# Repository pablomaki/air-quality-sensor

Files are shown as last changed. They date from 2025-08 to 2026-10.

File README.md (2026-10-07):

# Air Quality Sensor

This repository contains the firmware, hardware design, and scripts for an indoor air quality sensor.

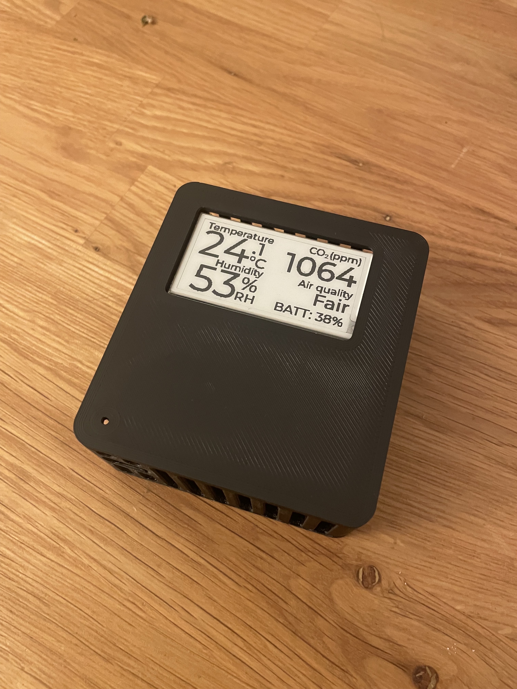
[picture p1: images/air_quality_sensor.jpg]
Air Quality Sensor


## Features

- **Supported Sensors**: The system supports a variety of sensors for measuring air quality parameters such as:
  - **SHT40/SHT41** temperature and humidity sensor
  - **SGP40** VOC (Volatile Organic Compound) sensor
  - **SCD40/SCD41** Carbon Dioxide (CO2) sensor (includes temperature and humidity reading as well)
  - **BMP390** Pressure sensor
  - **BME680** Gas, humidity, pressure and temperature sensor
- **Electronic paper display**: Support for an Electronic paper display for displaying the measured values.
- **Wireless Communication**: Matter over Thread, so the sensor works with any Matter controller (Apple Home, Google Home, Home Assistant). Bluetooth Low Energy is used only for commissioning.
- **Battery powered**: Battery life sensor and measurement/advertisement frequency dependent, but the default configurations aim for 1+ month up time.
- **Dockerized data receiver**: Joins the sensor's Matter fabric as a second administrator, alongside the smart home controller, and republishes the measurements to Prometheus and to an MQTT server ([MQTTThing](https://github.com/arachnetech/homebridge-mqttthing)).

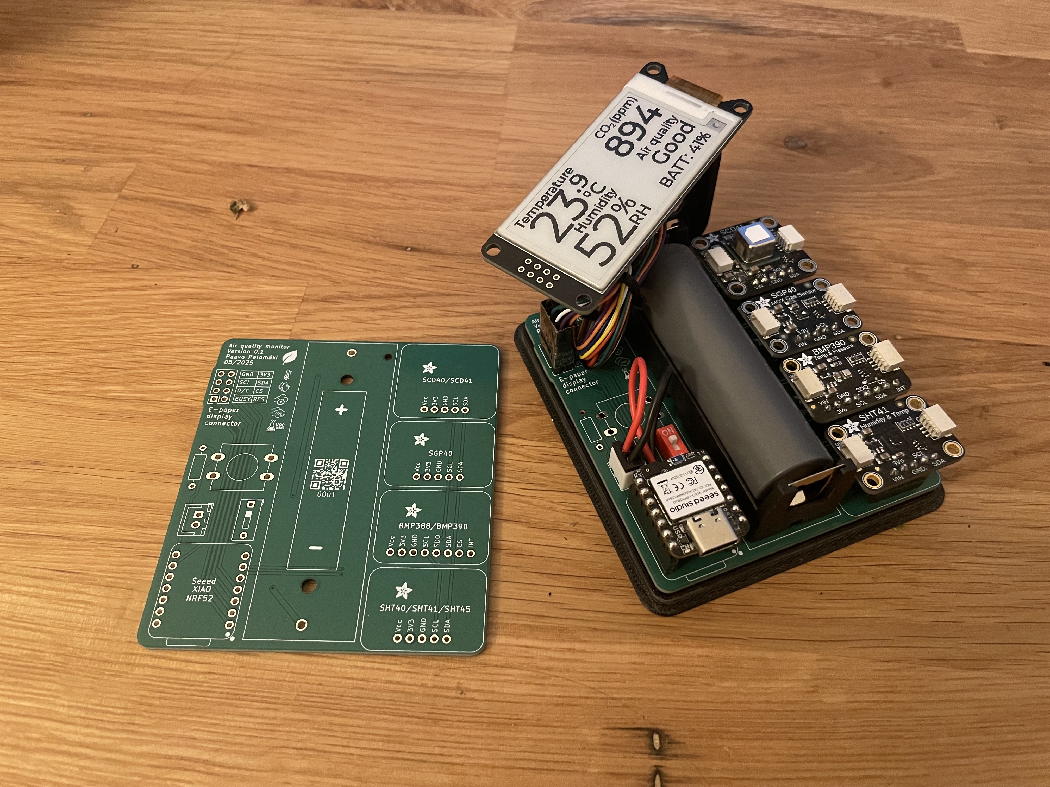
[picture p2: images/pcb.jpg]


## Structure

- **docker/**: Contains Docker configuration files for setting up the Matter sensor reader.
- **firmware/**: Contains the firmware source code and build files for the air quality sensor.
- **pcb/**: Contains the design files for the air quality sensor PCB.
- **enclosure/**: Contains the design files for the air quality sensor enclosure.
- **scripts/**: Contains utility scripts for reading the air quality sensor over Matter and forwarding the data to Prometheus and MQTT, used by the docker image.

Refer to the README files in each subdirectory for more details.

## TODO
- **Firmware**
    -
- **PCB**
    -
- **Scripts**
    -
- **Other**
    -

## License

This project is licensed under the terms specified in the `LICENSE` file.

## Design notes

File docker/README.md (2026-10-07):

# Docker

Deployment for the host that reads the air quality sensors over Matter and
forwards their measurements to Prometheus and MQTT.

## Files

- **docker-compose.yml**: Defines the Matter server and the bridge service.
- **Dockerfile**: Builds the image for the scripts in [scripts/](../scripts/).

## Services

- **matter-server**: Upstream
  [python-matter-server](https://github.com/home-assistant-libs/python-matter-server).
  It owns the Matter fabric, holds the subscriptions to the sensors and exposes
  them on a WebSocket API at port 5580. Its fabric credentials live in
  `./matter-server-data`, so back that directory up - losing it means
  re-commissioning every sensor.
- **aqs_matter_client**: The bridge, serving Prometheus metrics on port 8000.

Both run with `network_mode: host`, which is required: Matter needs IPv6 and
mDNS on the LAN to reach the sensors through the Thread border router, and
neither survives Docker's default bridge network. See the
[scripts README](../scripts/README.md) for the IPv6 route configuration the host
itself needs.

Unlike the old BLE setup there is one bridge container for all sensors, not one
per sensor - they share a single Matter fabric, and metrics are told apart by
the `sensor` label.

## Usage

Review the environment variables in `docker-compose.yml`, in particular
`NODE_NAMES` and the MQTT broker settings, then start both services:

```bash
docker compose up -d --build
```

Commission the sensors into the fabric before expecting any metrics; the
[scripts README](../scripts/README.md) covers that. To check that the bridge
works, follow its logs:

```bash
docker compose logs -f aqs_matter_client
```

Or scrape the metrics endpoint directly:

```bash
curl -s http://localhost:8000/metrics | grep aqs_
```

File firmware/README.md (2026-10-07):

# Air Quality Sensor Firmware for nRF52840

## Overview

This firmware runs on the Seeed XIAO nRF52840 (Sense) board. It reads a set of air
quality sensors over I2C and exposes the readings as a **Matter over Thread** device,
so the node can be commissioned into any Matter ecosystem.

### Key Features

- **Sensor Support**: The firmware supports the following sensors. Which of them are
  present is decided by the board overlay, see [Sensor selection](#sensor-selection):
  - **SHT40/SHT41** temperature and humidity sensor
  - **SGP40** VOC (Volatile Organic Compound) sensor
  - **SCD40/SCD41** Carbon Dioxide (CO2) sensor (also measures temperature and humidity,
    used as a fallback when no dedicated sensor is present)
  - **BMP390** pressure sensor
  - **BME680** gas/IAQ sensor (requires the `bsec` west manifest group, see
    [Prerequisites](#prerequisites))
- **Matter over Thread**: The node is commissioned over Bluetooth LE and then reports
  over Thread. Bluetooth LE is used only for commissioning.
- **Configurable sampling and reporting**: Independent intervals, see
  [Configuration](#configuration).
- **Per-board identity from one binary**: The onboarding values compiled into the
  image are only fallbacks, see [Device identity](#device-identity).
- **Factory reset without a button**: Power cycle the device five times in a row,
  see [Factory reset](#factory-reset).

### Matter data model

Each quantity is reported on its own endpoint so that ecosystems surface them as
separate sensors:

| Endpoint | Device type | Reports |
| --- | --- | --- |
| 1 | Temperature Sensor | temperature |
| 2 | Humidity Sensor | relative humidity |
| 3 | Pressure Sensor | pressure |
| 4 | Air Quality Sensor | air quality, CO2 concentration |

A quantity with no valid reading is reported as `null` rather than as a placeholder
value, so an unavailable sensor is distinguishable from a working one.

### Device identity

Factory data is disabled, so serial number, unique ID and setup discriminator would
otherwise come from the image and be identical on every board flashed with it - two
units would then present themselves to a controller as the same device. Instead
`src/components/device_identity.cpp` derives all three from the SoC's factory
programmed device ID on every boot and persists them:

| Value | Derivation |
| --- | --- |
| Serial number | `AQS-` followed by the device ID in hex |
| Unique ID | Salted SHA-256 of the device ID, so it is not the serial number restated |
| Setup discriminator | 12 bits of that same hash |

The derivation is deterministic, so a board keeps its identity across a factory reset
and a controller recognises a recommissioned unit as the same device. The setup
*passcode* is still shared, because a per-board one needs a SPAKE2+ verifier generated
on the device, which belongs with real factory data.

Because the discriminator now differs per board, the pairing code does too. Read it
from the log at startup, where the stack prints the QR code payload and the manual
pairing code - see [Viewing the log output](#viewing-the-log-output).

### Factory reset

A commissioned device stops advertising over Bluetooth LE, so if its fabric ever
becomes unusable it cannot be recommissioned without first being erased. The assembled
board carries no button, and flashing a `.uf2` does not help: the image is written to
the application partition only, leaving the settings partition that holds the
commissioning state untouched.

**Power cycle the device five times in a row**, leaving it powered for less than five
seconds each time. The LED blinks once per counted cycle. On the fifth the device
withdraws its records from the border router, erases the settings partition and
reboots uncommissioned, ready to be commissioned again.

Staying powered past the window drops the count, so ordinary restarts never accumulate.
Both numbers are configurable, see [Other settings](#other-settings).

## Building and Running

### Prerequisites

To build the project, ensure you have the following tools installed:

- [Visual Studio Code](https://code.visualstudio.com/download)
- [nRF Connect for Visual Studio Code](https://docs.nordicsemi.com/bundle/nrf-connect-vscode/page/get_started/install.html)
- nRF Connect SDK and Toolchain version 3.2.4 or newer

  > **Do not use v3.2.1.** Its `i2c_nrfx_twi` driver compares the transfer result
  > against `NRFX_SUCCESS` (0x0BAD0000) while the event handler stores 0 on success,
  > so every I2C transfer reports `-EIO` and no sensor is ever detected. The XIAO BLE
  > uses this driver for `i2c1`, where all the sensors live. Fixed in v3.2.4.

- The `bme68x` and `bsec` Bosch libraries (needed for `CONFIG_BME68X_IAQ`) belong to the
  `bsec` west manifest group, which is disabled by default. Enable it and fetch the
  sources before building:

  ```
  west config manifest.group-filter -- +bsec
  west update bme68x bsec
  ```

### Build Instructions

1. Clone the repository and navigate to the `firmware/` directory.
2. Open the project in Visual Studio Code.
3. Configure the build environment using the nRF Connect extension (v3.2.4 SDK and toolchain).
4. Build for the board target `xiao_ble/nrf52840/sense`.
5. Selecting "No sysbuild" might be necessary to avoid build issues.

Flash by copying the resulting `build/zephyr/zephyr.uf2` onto the mass storage device
that the Adafruit UF2 bootloader presents after double tapping reset. The firmware
deliberately does not use MCUboot, so that bootloader is left untouched.

### Viewing the log output

The console is a USB CDC ACM port provided by the board, not a UART. After flashing,
a second USB device enumerates; connect to it at any baud rate:

```
minicom -D /dev/ttyACM0
```

## Configuration

Settings live in `prj.conf` and are defined in `Kconfig`. There is no `config.h`.

### Sensor selection

The board overlay in `boards/` is the single source of truth for which parts exist on
the board. Adding a node there enables both the Zephyr driver and the application
support for it, because each `CONFIG_ENABLE_*` symbol depends on the corresponding
devicetree node and defaults to `y`. Use `prj.conf` only to turn a present sensor
*off*:

```
CONFIG_ENABLE_SHT4X=n   # part is on the board but not used in this build
```

Flash is very tight on this target, so check the memory report after a build and
enable sensors one at a time.

`CONFIG_BME68X_IAQ` is the exception: it is the licensed Bosch BSEC path, has no
devicetree default, and is mutually exclusive with the plain `CONFIG_BME680` driver.

### Timing

| Symbol | Default | Meaning |
| --- | --- | --- |
| `CONFIG_SAMPLE_INTERVAL_MS` | 5000 | How often every enabled sensor is read. Also the sampling interval given to the Sensirion gas index algorithm. |
| `CONFIG_REPORT_INTERVAL_MS` | 60000 | How often the Matter attributes are refreshed from the buffered samples. |

The two are independent. The number of samples averaged into each reported value is
derived from them - one reporting period's worth - so every sample taken contributes
to exactly one report.

Note that when a controller actually *receives* a value is governed by its own Matter
subscription intervals, not by `CONFIG_REPORT_INTERVAL_MS`, which only controls how
fresh the attributes are.

### Other settings

| Symbol | Meaning |
| --- | --- |
| `CONFIG_ENABLE_EVENT_LED` | Blink the RGB LED on application events |
| `CONFIG_FACTORY_RESET_POWER_CYCLES` | Power cycles in succession that trigger a factory reset |
| `CONFIG_FACTORY_RESET_POWER_CYCLE_WINDOW_MS` | How long the device must stay up before the count is dropped |
| `CONFIG_SCD4X_ALTITUDE` | Altitude in metres, used when no pressure sensor supplies compensation |
| `CONFIG_SCD4X_TEMPERATURE_OFFSET_MILLI_C` | Compensates the SCD4x self heating, in milli-degrees Celsius (2.35 degrees = 2350) |

## Additional Resources

- [Nordic Semiconductor Documentation](https://docs.nordicsemi.com/)
- [Seeed XIAO nRF52840 Documentation](https://wiki.seeedstudio.com/XIAO_nRF52840/)

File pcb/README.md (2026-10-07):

# PCB Design

This directory contains the PCB design files for the air quality sensor.

## Files

- **air-quality-sensor-pcb.kicad_pcb**: The PCB layout file.
- **air-quality-sensor-pcb.kicad_prl**: Project-related layout file.
- **air-quality-sensor-pcb.kicad_pro**: KiCad project file.
- **air-quality-sensor-pcb.kicad_sch**: The schematic file for the PCB design.
- **gerber.zip**: Gerber files for ordering the PCB.

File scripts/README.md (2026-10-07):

# Scripts

Utility scripts for reading the air quality sensor over Matter and forwarding its
measurements to Prometheus and MQTT.

The sensor is a Matter over Thread device. It has no vendor cloud and no local
HTTP API, so the only way to read it is to speak Matter to it. This host does
that by joining the sensor's Matter fabric as a second administrator, alongside
Apple Home - Matter's multi-admin support means both controllers see the device
at the same time and neither disturbs the other.

Reading the values back out of Apple Home instead is not possible: Apple exposes
no local API for accessory state, so the data has to come from the device.

## Files

- **aqs_matter_client.py**: Subscribes to the sensors' Matter attributes through
  a [python-matter-server](https://github.com/home-assistant-libs/python-matter-server)
  instance, exposes them as Prometheus metrics and publishes them to MQTT.
- **aqs_matter_commission.py**: Joins a sensor to this host's Matter fabric.
- **aqs_matter_nodes.py**: Lists the nodes on the fabric and removes unwanted ones.

Both scripts are run by the containers defined in [docker/](../docker/); see that
directory's README for the deployment.

## Exported metrics

Every metric carries `sensor` and `node_id` labels, so one process serves all
sensors on the fabric.

| Metric | Unit | Matter cluster |
| --- | --- | --- |
| `aqs_temperature_celsius` | °C | Temperature Measurement (0x0402) |
| `aqs_humidity_percent` | % RH | Relative Humidity Measurement (0x0405) |
| `aqs_pressure_hpa` | hPa | Pressure Measurement (0x0403) |
| `aqs_co2_ppm` | ppm | CO2 Concentration Measurement (0x040D) |
| `aqs_air_quality` | 0 unknown … 6 extremely poor | Air Quality (0x005B) |
| `aqs_node_available` | 0 or 1 | reachability, from the Matter server |
| `aqs_last_update_timestamp_seconds` | unix time | last attribute report received |
| `aqs_bridge_connected` | 0 or 1 | bridge to Matter server connection |

A measurement the firmware reports as null - no valid sample - is removed from
the metrics rather than published as zero, so it reads as absent in Prometheus.

The same values are published to MQTT as `<sensor name>/<measurement>`, matching
the topic layout the old BLE client used, with `air_quality` published as its
readable name for [MQTTThing](https://github.com/arachnetech/homebridge-mqttthing).

The VOC and IAQ indices the BLE firmware exposed are not available: the firmware
folds them into the Air Quality rating and does not publish the raw index over
Matter. Battery level is likewise not published.

## Dependencies

- **Python 3.9+**
- **`aiohttp`** - WebSocket client for the Matter server
- **`paho-mqtt`** - MQTT communication
- **`prometheus-client`** - Metrics collection and HTTP server
- A running **python-matter-server**, see [docker/](../docker/)

## Host setup

The sensor is a Thread minimal end device with no IP connectivity of its own.
This host reaches it over IPv6 through a Thread border router - an Apple TV or
HomePod if the sensor is in Apple Home - which advertises a route to the Thread
mesh prefix on the LAN. Linux ignores those advertisements by default, so enable
them for the LAN interface:

```bash
sudo tee /etc/sysctl.d/99-thread.conf <<'EOF'
net.ipv6.conf.eth0.accept_ra = 2
net.ipv6.conf.eth0.accept_ra_rt_info_max_plen = 64
EOF
sudo sysctl -p /etc/sysctl.d/99-thread.conf
```

Replace `eth0` with the actual interface. Verify that a route to the mesh prefix
appears, which needs the border router to be up:

```bash
ip -6 route show | grep -i fd
```

Containers speaking Matter must use host networking; IPv6 and mDNS do not
survive Docker's default bridge.

Matter discovers devices over mDNS, and its Linux implementation does that
through the host's Avahi daemon rather than resolving on its own. Avahi has to
be installed and running, and its D-Bus socket has to be visible to the Matter
server container - which is what the `/run/dbus` mount in the compose file is
for:

```bash
sudo apt install avahi-daemon
sudo systemctl enable --now avahi-daemon
```

## Adding a sensor to this host's fabric

If the sensor is already in Apple Home, open pairing mode there rather than
factory resetting it - that keeps the Apple Home pairing intact and adds this
host as a second administrator:

1. In the Home app, open the accessory's settings.
2. Choose *Turn On Pairing Mode* and note the setup code it shows.
3. Run the commissioning helper with that code:

```bash
docker exec -it aqs_matter_client python aqs_matter_commission.py 1234-567-8901
```

The helper prints the node id the sensor was assigned. Put it in `NODE_NAMES` in
[docker-compose.yml](../docker/docker-compose.yml) to control the `sensor` label
its metrics carry, then restart the bridge.

For a factory-fresh sensor that is not in any fabric yet, commissioning has to
run over Bluetooth and has to supply the Thread network credentials first. Start
the Matter server with `--bluetooth-adapter 0`, push the dataset, then pair with
the code from the sensor's onboarding label:

```bash
docker exec -it aqs_matter_client python aqs_matter_commission.py --ble 1234-567-8901
```

## Managing the fabric

List what the Matter server currently holds:

```bash
docker exec -it aqs_matter_client python aqs_matter_nodes.py list
```

A failed commissioning attempt leaves a node entry behind that will always read
as unreachable, because no device was ever paired to it. Remove those:

```bash
docker exec -it aqs_matter_client python aqs_matter_nodes.py remove 1 2
```

Removing a node that is genuinely paired also tells the device to drop this
fabric, so it stops reporting here; it stays in any other controller's fabric,
such as Apple Home. Removing a leftover entry only clears the server's own
storage, since there is no device on the other end to inform.

## Troubleshooting commissioning

`Commission with code failed` means the Matter server never completed the
pairing. The reason is in its own log, which is far more specific than the
helper's error:

```bash
docker compose logs --tail=100 matter-server
```

The usual causes, all of which the helper cannot distinguish between:

- **The device was never discovered.** Check that Avahi is running on the host
  and that the Matter server container has `/run/dbus` mounted. Confirm the
  sensor is actually advertising while pairing mode is open:

  ```bash
  avahi-browse -rt _matterc._udp
  ```

  An empty result means either pairing mode is closed or the border router is
  not relaying the Thread mesh's mDNS onto the LAN.

- **The device was discovered but could not be reached.** This is the IPv6 route
  described above: without it the host resolves the sensor's address and then
  cannot route to it. Verify with `ip -6 route show | grep -i fd`, and ping the
  address `avahi-browse` reported.

- **The commissioning window expired.** It is open for a limited time, and the
  code changes every time it is reopened. Open pairing mode in the Home app
  immediately before running the helper, not minutes ahead.

- **The fabric limit was reached.** The firmware allows five, so this only
  happens after repeated failed attempts have left stale fabrics behind.

## Running outside Docker

```bash
pip install aiohttp paho-mqtt prometheus-client
MATTER_SERVER_URL=ws://localhost:5580/ws PROMETHEUS_PORT=8000 python -u aqs_matter_client.py
```

## Configuration

Both scripts are configured through environment variables.

| Variable | Default | Description |
| --- | --- | --- |
| `MATTER_SERVER_URL` | `ws://localhost:5580/ws` | Matter server WebSocket API |
| `NODE_NAMES` | *(empty)* | `<node id>:<name>` pairs, comma separated |
| `PROMETHEUS_PORT` | `8000` | Port the metrics endpoint listens on |
| `BROKER` | *(empty)* | MQTT broker address; empty disables MQTT |
| `PORT` | `1883` | MQTT broker port |
| `USERNAME` | *(empty)* | MQTT username |
| `PASSWORD` | *(empty)* | MQTT password |

Without `NODE_NAMES` a sensor is named from its Matter NodeLabel, falling back to
its ProductName and then to `node_<id>`.

## Notes on reporting rate

The bridge never polls. It holds a Matter subscription and the sensors push
reports to it, so how often values change is set by the firmware's
`CONFIG_REPORT_INTERVAL_MS` and by the subscription intervals the Matter server
negotiates. Scraping Prometheus faster than the firmware reports just re-reads
the last value; use `aqs_last_update_timestamp_seconds` to alert on a sensor that
has gone quiet.

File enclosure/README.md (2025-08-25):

# Enclosure Design

This directory contains the enclosure design files for the air quality sensor.

The enclosure attaches to the pcb using two M3 screws that attach to the heat insert nuts on the enclosure bottom. The screen is friction fit to the top part of the enclosure and finally, the top of the enclosure is friction fit on the bottom part. Some sanding might be required depending on the 3D printer tolerances.

## Files

- **enclosure.step**: Full 3D model of the enclosure in STEP format including the necessary components excluding the battery mount.
- **enclosure_bottom.stl**: Step file for the bottom part of the enclosure design.
- **enclosure_top.stl**: Step file for the top part of the enclosure design.

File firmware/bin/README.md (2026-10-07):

# Firmware binaries

Pre-compiled firmware images for the sensor configurations defined in
`firmware/variants/`. Each image is a Matter over Thread device, commissioned
over Bluetooth LE and reporting over Thread.

Rebuild them with:

```sh
cd firmware
./scripts/build_variants.sh            # all variants
./scripts/build_variants.sh aqs_001    # just one
```

The script writes each image here, named after its variant.

## Files

### aqs_001.uf2 - temperature, humidity and CO2

**Board:** XIAO BLE Sense (`xiao_ble/nrf52840/sense`)

**Fitted sensors:**
- SHT41, temperature and humidity
- SCD41, carbon dioxide

**Reports:** temperature, relative humidity and CO2 concentration. The air
quality attribute reads `Unknown`, since rating the air needs a VOC or IAQ
sensor and this variant has neither.

**Configuration:** sampling every 10 s, Matter attributes refreshed every 60 s,
product name `Air Quality Sensor TH-CO2`.

### aqs_002.uf2 - VOC only

**Board:** XIAO BLE Sense (`xiao_ble/nrf52840/sense`)

**Fitted sensors:**
- SGP40, volatile organic compounds

**Reports:** an air quality rating derived from the VOC index.

**Configuration:** sampling every 5 s to suit the Sensirion gas index algorithm,
Matter attributes refreshed every 60 s, product name `Air Quality Sensor VOC`.

Without a temperature and humidity sensor the SGP40 cannot be compensated and
falls back to the driver's defaults, which costs some accuracy.

### aqs_003.uf2 - Bosch IAQ

**Board:** XIAO BLE Sense (`xiao_ble/nrf52840/sense`)

**Fitted sensors:**
- BME680, gas/IAQ and pressure

**Reports:** temperature, relative humidity, pressure, and an air quality rating
derived from the IAQ index. The temperature and humidity come from BSEC's heat
compensated outputs, which correct for the gas heater.

**Configuration:** product name `Air Quality Sensor IAQ`. Requires the licensed
Bosch BSEC library, so the `bsec` west manifest group has to be enabled before
building.

### aqs_004.uf2 - CO2 plus Bosch IAQ

**Board:** XIAO BLE Sense (`xiao_ble/nrf52840/sense`)

**Fitted sensors:**
- SCD41, carbon dioxide
- BME680, gas/IAQ and pressure

**Reports:** everything the data model carries - temperature, relative humidity,
pressure, CO2 concentration and an air quality rating from the IAQ index. The
temperature and humidity come from the BME680's heat compensated outputs, and
the CO2 from the SCD41, whose own gas estimate is not used.

The BME680 is read before the SCD41, so its pressure reading feeds the SCD41's
pressure compensation, which is more accurate than the configured altitude.

**Configuration:** product name `Air Quality Sensor CO2-IAQ`. Requires the
licensed Bosch BSEC library, as `aqs_003` does.

Not built yet: run `./scripts/build_variants.sh aqs_004` to produce it. It is the
heaviest of the variants, so check the flash figure in the build output.

## Endpoints without a source

The Matter data model is the same in every image: endpoint 1 temperature,
2 humidity, 3 pressure, 4 air quality and CO2. A quantity that no fitted sensor
measures is reported as `null` rather than as a placeholder value.

| | aqs_001 | aqs_002 | aqs_003 | aqs_004 |
| --- | --- | --- | --- | --- |
| Temperature | SHT41 | `null` | BME680 | BME680 |
| Humidity | SHT41 | `null` | BME680 | BME680 |
| Pressure | `null` | `null` | BME680 | BME680 |
| CO2 | SCD41 | `null` | `null` | SCD41 |
| Air quality | `Unknown` | from VOC | from IAQ | from IAQ |

Temperature and humidity are taken from the best fitted source, preferring a
dedicated SHT41, then the BME680, then the SCD41.

The air quality rating comes from a gas sensor only. A CO2 concentration on its
own says how well a room is ventilated, not what is in the air, so `aqs_001`
reports the CO2 value and leaves the rating `Unknown`. The BME680 likewise
estimates CO2 and VOC from its gas resistance, but those are not published, since
they are not comparable with a real CO2 measurement.

## Installation Instructions

1. **Enter Bootloader Mode:**
   - Doubleclick the reset button on the XIAO BLE board
   - Device will mount as a USB mass storage device

2. **Flash Firmware:**
   - Copy the desired `.uf2` file to the mounted device
   - Device will automatically reboot with new firmware

3. **Verify Installation:**
   - Connect to the USB CDC ACM console that enumerates after reboot
     (`/dev/ttyACM*`) and check the sensor initialization and measurement output

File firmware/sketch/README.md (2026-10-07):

# `sketch/` — proposed firmware architecture

Design-only material. Nothing here is built or linked; `sketch/` is excluded from the
build (no `CMakeLists.txt`, and it should be added to `.gitignore`-adjacent tooling
only if you don't want it committed — otherwise keep it as living design docs).

- [`REVIEW.md`](REVIEW.md) — how the firmware on `feat-redesign` actually stands against
  the plan below: what already aligns, 14 findings worst-first, and a suggested order of work.
- [`ARCHITECTURE.md`](ARCHITECTURE.md) — the plan: layers, modules, file layout,
  RTOS usage, Matter mapping, configuration tiers, power, testing, migration steps.

Rough interface sketches carrying the load-bearing decisions — illustrative, not
compilable:

| File | Decision it pins down |
|---|---|
| [`skeletons/aqs_sensor.h`](skeletons/aqs_sensor.h) | The sensor plug-in contract: self-registering descriptors, optional per-part ops, warm-up/duty-cycle fields |
| [`skeletons/aqs_state.h`](skeletons/aqs_state.h) | One aggregated snapshot, copy-out access, explicit per-value status |
| [`skeletons/sensor_hub.c`](skeletons/sensor_hub.c) | Per-sensor delayable work + state machine, drift-free cadence, backoff/recovery |
| [`skeletons/telemetry.c`](skeletons/telemetry.c) | The two clocks: sample consumption vs. the configurable report interval |
| [`skeletons/matter_reporting.cpp`](skeletons/matter_reporting.cpp) | The C++/CHIP wall: binding table, cluster unit scaling, NULL for absent values |
| [`skeletons/Kconfig.sketch`](skeletons/Kconfig.sketch) | Config shape: DT-gated sensor symbols, cadence defaults, RTOS resources in one auditable place |

`ARCHITECTURE.md` was written before reading the current sources; `REVIEW.md` is the
reconciliation with what is actually in `src/` today.

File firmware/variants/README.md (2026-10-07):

# Build variants

One overlay plus one conf fragment per product variant, layered on top of
`prj.conf` and the board overlay rather than replacing them. Nothing in
`prj.conf` changes between variants.

## Why the overlay decides the sensors

Each `CONFIG_ENABLE_<sensor>` symbol depends on the matching devicetree node and
defaults to `y`:

```kconfig
config ENABLE_SHT4X
    bool "Enable SHT4X sensor"
    depends on DT_HAS_SENSIRION_SHT4X_ENABLED
    default y
```

`DT_HAS_SENSIRION_SHT4X_ENABLED` is generated by the build whenever a node has
`compatible = "sensirion,sht4x"` and `status = "okay"`. So enabling a node in the
variant overlay turns on the Zephyr driver *and* the application support for it,
with no Kconfig entry anywhere. The conf fragment carries only what the
devicetree cannot express - the BSEC licence path, product name, altitude,
timing.

If you ever want a fitted part deliberately switched off in one build, add
`CONFIG_ENABLE_<sensor>=n` to that variant's fragment. That works and is silent.
The reverse - `=y` for a part whose node is disabled - cannot force it on: the
`depends on` wins and Kconfig warns, naming the unsatisfied dependency.

## Building

`EXTRA_DTC_OVERLAY_FILE` and `EXTRA_CONF_FILE` are additive, so the base
`prj.conf` and board overlay still apply underneath:

```sh
west build -b xiao_ble/nrf52840/sense -d build/aqs_001 -- \
    -DEXTRA_DTC_OVERLAY_FILE=variants/aqs_001.overlay \
    -DEXTRA_CONF_FILE=variants/aqs_001.conf
```

Separate `-d` directories let the variants coexist without rebuilding each
other. To build them all:

```sh
for v in aqs_001 aqs_002 aqs_003; do
    west build -b xiao_ble/nrf52840/sense -d "build/$v" -- \
        -DEXTRA_DTC_OVERLAY_FILE="variants/$v.overlay" \
        -DEXTRA_CONF_FILE="variants/$v.conf" || break
done
```

In the nRF Connect extension, add one build configuration per variant and put
the two `-D` arguments in "Extra CMake arguments".

## Two one-time changes this needs

**1. Label the sensor nodes** in `boards/xiao_ble_nrf52840_sense.overlay`, so the
variant overlays can refer to them:

```dts
sht4x: sht4x@44  { ... };
sgp40: sgp40@59  { ... };
scd41: scd41@62  { ... };
bmp390: bmp390@77 { ... };
bme680: bme680@77 { ... };
```

Leave them all `status = "disabled"` there. The base overlay then describes what
the board *can* carry, and each variant says what is actually fitted. Building
without a variant gives a node with no sensors, which is a clearer default than
an arbitrary set.

**2. Delete the per-sensor lines from `prj.conf`**, so the devicetree defaults
win. Without this the shared baseline overrides every variant:

```
CONFIG_ENABLE_SHT4X=y     <- remove
CONFIG_ENABLE_SGP40=n     <- remove
CONFIG_ENABLE_SCD4X=y     <- remove
CONFIG_ENABLE_BMP390=n    <- remove
CONFIG_ENABLE_BME680=n    <- remove
```

Keep `CONFIG_ENABLE_EVENT_LED` - it has no devicetree node behind it, so it is a
plain application choice and belongs in the shared baseline.

## Adding a variant

1. Copy an overlay and set each of the five sensors to `okay` or `disabled`.
2. Copy a conf fragment only if the variant needs something beyond sensor
   selection.

Remember the BME680 and BMP390 share address 0x77 and cannot both be enabled.

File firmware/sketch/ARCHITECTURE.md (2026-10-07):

# Air Quality Sensor firmware — proposed architecture

Target: nRF52840 (Cortex-M4F, 1 MB flash / 256 KB RAM), nRF Connect SDK v3.2.1,
Matter over Thread, USB powered today, battery-capable later.

---

## 1. Requirements that shape the design

| # | Requirement | Architectural consequence |
|---|---|---|
| R1 | Many possible sensors, selected per build/board | Sensors must be **plug-ins**: adding one touches only its own files + a devicetree node. No `switch` statements in core code. |
| R2 | Report every X seconds, X configurable | Sampling cadence and *reporting* cadence are **separate clocks**. X lives in a runtime-settable, persisted setting — not only in Kconfig. |
| R3 | Matter over Thread | The CHIP stack owns its own thread and its own locking. Everything C++ stays behind one wall. |
| R4 | USB now, battery maybe | No busy-waiting, no polling loops, all work is timer/event driven, sensor power gating modelled from day one even if unused. |
| R5 | Maintainable | One responsibility per module, one direction of dependency, logic testable on `native_sim` without hardware. |

## 2. Design principles

1. **Devicetree says what exists; Kconfig says what to do with it; Settings says what the user changed.** Three tiers, never duplicated.
2. **Sensors are Zephyr `sensor` devices.** If a sensor has no upstream driver, write an out-of-tree driver implementing `sensor_driver_api` in `drivers/sensor/` — do *not* put I²C transactions in application code. The application then knows exactly one sensor API forever.
3. **One direction of dependency.** `platform → sensing → aq → matter`. Nothing below reaches up. The Matter layer is the only consumer of the aggregated state; the sensing layer has never heard of Matter.
4. **C++ is quarantined.** Only `src/matter/` is C++. Everything else is C with `extern "C"` headers. This keeps the reusable parts testable and the CHIP include-storm contained.
5. **Blocking I/O never runs on the system workqueue.** Sensor reads take tens of milliseconds (and seconds of warm-up); they get their own workqueue with its own stack.
6. **A missing value is `null`, not `0`.** Every value carries a status; unavailable Matter attributes are written as NULL.

## 3. Layered view

```
                +-----------------------------------------------+
                |  Matter / CHIP (C++)                          |
   endpoints,   |  matter_app  matter_reporting  matter_ota     |
   ZAP, OTA     |  matter_endpoints  matter_identify            |
                +------------------------^----------------------+
                                         | aqs_state snapshot (read-only)
                +------------------------+----------------------+
   domain       |  aq: aggregation, filtering, indices          |
   logic (C)    |  aq_state  aq_index  gas_index                |
                +------------------------^----------------------+
                                         | zbus: CHAN_SENSOR_SAMPLE
                +------------------------+----------------------+
   acquisition  |  sensing: sensor_hub (scheduler + registry)   |
   (C)          |  per-sensor glue modules (warm-up, quirks)    |
                +------------------------^----------------------+
                                         | Zephyr sensor API
                +------------------------+----------------------+
   drivers      |  upstream drivers  |  out-of-tree drivers/    |
                +------------------------^----------------------+
                                         | devicetree
                +------------------------+----------------------+
   platform     |  settings  watchdog  leds  buttons  power     |
                |  fault_handler  shell/diag                    |
                +-----------------------------------------------+
```

## 4. File layout

```
firmware/
├── CMakeLists.txt                 # thin: adds subdirs, iterable sections, ZAP glue
├── Kconfig                        # menu "Air Quality Sensor", sources module Kconfigs
├── prj.conf                       # baseline that every build needs
├── VERSION                        # single source of version for MCUboot + Matter
├── sysbuild.conf                  # MCUboot on/off
├── west.yml (or rely on parent)   # pin NCS v3.2.1
│
├── configs/                       # composable conf fragments, selected on the CLI
│   ├── matter-thread.conf
│   ├── dfu-ota.conf               # Matter OTA requestor + MCUboot
│   ├── dfu-smp.conf               # BLE SMP fallback if OTA doesn't fit
│   ├── debug.conf                 # shell, RTT, asserts, verbose logs
│   ├── release.conf               # log minimal, no shell, watchdog on
│   └── lowpower.conf              # future: MTD/SED, PM_DEVICE_RUNTIME
│
├── boards/                        # overlays: which sensors are populated
│   ├── nrf52840dk_nrf52840.overlay
│   └── aqs_v1_nrf52840.overlay
├── boards/arm/aqs_v1/             # the custom board, once the PCB is real
│
├── dts/bindings/sensor/           # bindings for out-of-tree drivers
├── drivers/sensor/<part>/         # out-of-tree Zephyr sensor drivers
│
├── include/aqs/                   # the only headers other modules may include
│   ├── quantity.h                 # enum aqs_quantity + units + names
│   ├── value.h                    # struct aqs_value (value + status + timestamp)
│   ├── state.h                    # aggregated snapshot API
│   ├── sensor.h                   # the sensor plug-in contract
│   ├── config.h                   # runtime config get/set (report interval, offsets)
│   └── events.h                   # zbus channel declarations
│
├── src/
│   ├── main.c                     # ~40 lines: init platform, sensing, matter, done
│   ├── platform/
│   │   ├── settings_store.c       # NVS-backed runtime config, settings handlers
│   │   ├── watchdog.c             # WDT + per-thread heartbeat supervisor
│   │   ├── led_indication.c       # status pattern from app state
│   │   ├── button_handler.c       # factory reset, commissioning window
│   │   ├── power.c               # PM policy, sensor rail gating, battery hook
│   │   └── fault_handler.c        # fatal error capture, retained reboot reason
│   ├── sensing/
│   │   ├── sensor_hub.c           # registry iteration + per-sensor state machine
│   │   ├── sensor_wq.c            # dedicated workqueue definition
│   │   └── glue/
│   │       ├── scd4x.c            # CO2: 5 s cadence, ASC, pressure/temp offset
│   │       ├── sen5x.c            # PM/VOC/NOx: fan warm-up, duty cycling
│   │       ├── bme68x.c           # T/RH/P (+ optional BSEC)
│   │       ├── sht4x.c
│   │       ├── sgp4x.c            # raw ticks -> gas index algorithm
│   │       └── sim.c              # synthetic sensor: full pipeline, no hardware
│   ├── aq/
│   │   ├── aq_state.c             # owns the snapshot, mutex, staleness expiry
│   │   ├── aq_filter.c            # per-quantity median/EMA, spike rejection
│   │   ├── aq_index.c             # composite air quality -> Matter AirQualityEnum
│   │   └── gas_index.c            # wrapper around Sensirion gas index algorithm
│   ├── matter/
│   │   ├── matter_app.cpp         # stack init, event handler, commissioning
│   │   ├── matter_endpoints.cpp   # endpoint enable/disable from sensor set
│   │   ├── matter_reporting.cpp   # snapshot -> attributes, on the CHIP thread
│   │   ├── matter_identify.cpp
│   │   ├── matter_ota.cpp
│   │   └── default_zap/           # existing generated data model
│   └── diag/
│       └── shell_cmds.c           # `aqs sensors`, `aqs read`, `aqs interval 30`
│
├── tests/                         # ztest, run with twister on native_sim
│   ├── aq_index/
│   ├── aq_filter/
│   ├── aq_state/
│   └── sensor_hub/                # against a fake sensor device
└── sketch/                        # this design material
```

## 5. Module catalogue

| Module | Owns | Never does |
|---|---|---|
| `platform/settings_store` | Persisted runtime config, change notification | Know what the settings mean |
| `platform/watchdog` | Hardware WDT, heartbeat registration | Decide what a fault means |
| `platform/power` | PM policy, sensor rail gating, battery voltage | Touch sensors directly (goes via regulator DT) |
| `sensing/sensor_hub` | Iterate the sensor registry, run each sensor's state machine, publish samples | Know any specific part number |
| `sensing/glue/*` | One part's quirks: warm-up, calibration, channel→quantity mapping | Know about Matter, zbus, or other sensors |
| `aq/aq_state` | The single aggregated snapshot + validity/staleness | Format or transmit anything |
| `aq/aq_filter` | Smoothing, plausibility limits | Persist anything |
| `aq/aq_index` | Composite index from available quantities | Know cluster IDs |
| `matter/matter_reporting` | Snapshot → attribute writes, cadence, null handling | Compute values |
| `matter/matter_endpoints` | Which endpoints/clusters are live for this hardware set | Sample anything |
| `diag/shell_cmds` | Human diagnostics | Exist in release builds |

## 6. Core data model

```c
/* include/aqs/quantity.h */
enum aqs_quantity {
    AQS_Q_TEMPERATURE,      /* degC      */
    AQS_Q_HUMIDITY,         /* %RH       */
    AQS_Q_PRESSURE,         /* hPa       */
    AQS_Q_CO2,              /* ppm       */
    AQS_Q_TVOC,             /* ppb       */
    AQS_Q_VOC_INDEX,        /* 1..500    */
    AQS_Q_NOX_INDEX,        /* 1..500    */
    AQS_Q_PM1_0,            /* ug/m3     */
    AQS_Q_PM2_5,
    AQS_Q_PM4_0,
    AQS_Q_PM10,
    AQS_Q_COUNT
};

/* include/aqs/value.h */
enum aqs_status { AQS_ABSENT, AQS_WARMING_UP, AQS_VALID, AQS_STALE, AQS_ERROR };

struct aqs_value {
    float          value;       /* canonical unit per quantity, above */
    enum aqs_status status;
    int64_t        timestamp;   /* k_uptime_get() of acquisition */
    uint8_t        source;      /* sensor index, for provenance/debug */
};
```

`float` is deliberate: the M4F has an FPU, the Matter concentration clusters carry
`single`, and fixed-point scaling per quantity is the kind of detail that produces
unit bugs. Floats stay out of ISRs and out of log hot paths.

The aggregated state is one array plus a mutex, accessed only by copy-out:

```c
struct aqs_state { struct aqs_value q[AQS_Q_COUNT]; uint8_t air_quality_index; };
void aqs_state_snapshot(struct aqs_state *out);   /* short mutex hold, memcpy */
```

Consumers never hold a pointer into the live state, so no consumer can stall a
producer, and the Matter layer can never read a half-updated set.

## 7. The sensor plug-in contract (R1)

A sensor glue module declares itself into an iterable linker section; `sensor_hub`
iterates and knows nothing about it. Presence is driven by devicetree so a board
overlay is the single source of truth:

```c
/* src/sensing/glue/scd4x.c */
#define DT_DRV_COMPAT sensirion_scd4x

#if DT_HAS_DRV_INST(0)
static const struct aqs_channel_map scd4x_maps[] = {
    { SENSOR_CHAN_CO2,         AQS_Q_CO2 },
    { SENSOR_CHAN_AMBIENT_TEMP, AQS_Q_TEMPERATURE },
    { SENSOR_CHAN_HUMIDITY,    AQS_Q_HUMIDITY },
};

AQS_SENSOR_DEFINE(scd4x,
    .dev          = DEVICE_DT_GET(DT_DRV_INST(0)),
    .maps         = scd4x_maps,
    .map_count    = ARRAY_SIZE(scd4x_maps),
    .min_period_ms = 5000,      /* device physics */
    .warmup_ms     = 0,
    .ops           = &scd4x_ops /* optional: post-init calibration, suspend */
);
#endif
```

**Adding a sensor is four mechanical steps** — driver (or reuse upstream), DT node in
the board overlay, one glue file, one `Kconfig` symbol + `zephyr_library_sources_ifdef`
line. Core files are untouched. That is the property worth protecting in review.

`ops` is a small optional vtable for the ~20 % of sensors that need more than
fetch/get: `init()`, `start_measurement()`, `stop_measurement()`, `apply_config()`
(altitude, temperature offset), `self_test()`.

## 8. RTOS usage

### 8.1 Execution contexts

| Context | Kind | Prio | Stack | Why |
|---|---|---|---|---|
| CHIP event loop | thread (NCS) | NCS default | `CONFIG_CHIP_TASK_STACK_SIZE` | Owns the data model; only place attributes are written |
| OpenThread | thread (NCS) | NCS default | NCS | Radio/stack |
| `aqs_sensor_wq` | dedicated workqueue | preemptible, ~10 | 2–3 KB | Blocking I²C, warm-up delays; must never sit on the system WQ |
| `aqs_telemetry` | thread (zbus subscriber) | ~7 | 1.5–2 KB | Consumes samples, filters, updates state, drives the report cadence |
| system workqueue | Zephyr | default | default | LEDs, buttons, settings commits — short, non-blocking work only |
| logging | Zephyr (deferred) | low | small | `CONFIG_LOG_MODE_DEFERRED` so logging never blocks a sensor read |
| shell | Zephyr | low | 2 KB | Debug builds only |

Three application threads total. On a part where Matter + Thread already claim most
of the 256 KB, thread count is a RAM budget line item — resist the temptation to give
every sensor a thread.

### 8.2 Sampling: one delayable work item per sensor

Each registered sensor gets a `struct k_work_delayable` submitted to `aqs_sensor_wq`,
plus a small state machine:

```
UNINIT ──probe ok──> IDLE ──due──> WARMUP ──warmup_ms──> FETCH ──ok──> publish ──> IDLE
   │                                                        │
   └──probe fail──> ERROR <──── N consecutive failures ──────┘
                      │
                      └── exponential backoff (1s → 60s cap), bus/power recovery,
                          quantities marked AQS_ERROR after grace period
```

Why work items rather than a thread per sensor, or one thread polling all sensors:

- Heterogeneous cadences (SCD4x 5 s, SEN5x 1 s, BME680 on demand) fall out naturally
  from per-sensor `k_work_reschedule`, with no lowest-common-denominator tick.
- One stack for all sensors.
- A slow or wedged sensor delays only its own next sample; it cannot stall the report
  cadence, because reporting reads the snapshot, not the sensors.
- Warm-up and duty cycling are just extra states — the same mechanism that will power
  gate a fan on battery.

Rescheduling is computed from an absolute base (`next += period`), not
`k_work_reschedule(period)` from completion time, so cadence does not drift by the
read duration.

### 8.3 Decoupling: zbus

```c
ZBUS_CHAN_DEFINE(chan_sensor_sample, struct aqs_sample_msg, ...);  /* hub -> telemetry */
ZBUS_CHAN_DEFINE(chan_aq_state,      struct aqs_state,      ...);  /* telemetry -> N   */
ZBUS_CHAN_DEFINE(chan_config,        struct aqs_config,     ...);  /* settings -> N    */
ZBUS_CHAN_DEFINE(chan_net_status,    struct aqs_net_msg,    ...);  /* matter -> LEDs   */
```

zbus buys the thing that matters for maintainability: **new consumers cost nothing**.
A local display, a BLE debug service, a threshold alarm, an SD logger — each is a new
observer, with no edit to the producer. Discipline: listeners run in the *publisher's*
context, so only trivial listeners (LED state, log) may be listeners; anything that
blocks (Matter, filtering) must be a subscriber with its own thread.

If you would rather not take the zbus dependency, the fallback is a single
`k_msgq` from hub to telemetry and a direct call into `aqs_state`. Same shape, less
extensibility; the interfaces above do not change.

### 8.4 The two clocks (R2)

- **Sample interval** — per sensor, bounded below by device physics.
- **Report interval `X`** — one `k_work_delayable` on the telemetry thread:
  snapshot → hand to Matter. Default from
  `CONFIG_AQS_REPORT_INTERVAL_S` (60), overridden by the persisted setting
  `aqs/report_interval`, changeable at runtime via shell today.

Important Matter nuance to document in the code: the app controls how fresh the
*attributes* are; when a controller actually receives data is governed by its own
**subscription** min/max intervals. So `X` is "how often the data model is refreshed",
and the app additionally calls the attribute-change reporting path so a subscribed
controller sees a change promptly. Optional `CONFIG_AQS_REPORT_ON_CHANGE` with
per-quantity deltas gives event-driven publishing between ticks; combined with a
maximum silence interval it is also the power-friendly mode for a battery build.

### 8.5 Crossing into CHIP

`matter_reporting` is the only place that touches the data model, and it does so
from the CHIP context:

```cpp
/* called from telemetry thread */
void aqs_matter_publish(const struct aqs_state *s) {
    auto *copy = new aqs_state(*s);                     /* or a small static queue */
    chip::DeviceLayer::PlatformMgr().ScheduleWork(WriteAll, reinterpret_cast<intptr_t>(copy));
}
```

Never `LockChipStack()` from the sensor path — `ScheduleWork` avoids priority
inversion against the radio stack entirely.

### 8.6 Synchronization inventory

Deliberately small: one mutex inside `aq_state`, zbus channel locks, `ScheduleWork`
for the CHIP boundary, `k_sem` only in driver code. No shared globals, no spinlocks in
application code, no dynamic allocation after init.

## 9. Configuration (three tiers)

| Tier | Answers | Where | Example |
|---|---|---|---|
| Devicetree | "What hardware is on this board?" | `boards/*.overlay`, board files | I²C address, sensor power rail, interrupt GPIO |
| Kconfig | "How does this build behave?" | `Kconfig`, `configs/*.conf` | `AQS_SENSOR_SCD4X`, `AQS_REPORT_INTERVAL_S`, stack sizes, log levels |
| Settings/NVS | "What did the user change?" | `platform/settings_store` | report interval, temperature offset, altitude, sensor enable at runtime |

Kconfig symbols are *defaults* for settings-backed values, so a factory reset gives a
known-good configuration. `AQS_SENSOR_*` symbols `depends on DT_HAS_<compat>_ENABLED`,
so you cannot enable a sensor that is not on the board.

Remote configuration of `X`: the honest options are (a) shell/UART today,
(b) a manufacturer-specific Matter cluster attribute — flexible, but most commercial
ecosystems ignore custom clusters, (c) leave cadence to the controller's subscription
parameters, which is the spec-blessed answer. Recommendation: build (a) now, keep the
setting plumbing generic, add (b) only if a specific controller needs it.

## 10. Matter data model mapping

Proposed endpoint layout (IDs to be confirmed against the spec revision your ZAP
targets — verify before generating):

| EP | Device type | Clusters | Populated when |
|---|---|---|---|
| 0 | Root Node | Basic Info, General/Thread Diagnostics, OTA Requestor, (Power Source, later) | always |
| 1 | Air Quality Sensor (0x002C) | Air Quality (0x005B), CO₂ (0x040D), PM1 (0x042C), PM2.5 (0x042A), PM10 (0x042D), TVOC (0x042E), + NO₂/O₃/CH₂O as needed | any AQ sensor |
| 2 | Temperature Sensor (0x0302) | Temperature Measurement (0x0402) | T available |
| 3 | Humidity Sensor (0x0307) | Relative Humidity Measurement (0x0405) | RH available |
| 4 | Pressure Sensor (0x0305) | Pressure Measurement (0x0403) | P available |

T/RH/P get their own endpoints so ecosystems surface them as separate sensor tiles;
the concentration clusters share endpoint 1 because they are distinct cluster IDs
under one device type.

**Variant handling** — ZAP is static, hardware is not. Two workable strategies:

1. *Superset ZAP + runtime pruning*: generate every cluster, then disable unpopulated
   endpoints at boot with `emberAfEndpointEnableDisable()` driven by the registry.
   One binary covers all variants; cost is a little flash and coarse granularity
   (endpoint, not individual cluster).
2. *Per-variant ZAP*: exact data model, but N ZAP files to keep in sync.

Recommendation: (1) while the sensor set is still moving, with the endpoint→quantity
table derived from the same registry the hub iterates, so the data model can never
disagree with the hardware. Revisit if certification pushes back on unpopulated
clusters on endpoint 1.

**Null handling**: measured-value attributes are nullable. `matter_reporting` writes
NULL for any quantity whose status is not `AQS_VALID`/`AQS_STALE`, and applies each
cluster's own unit and scaling in exactly one place per cluster (temperature is
0.01 °C int16, humidity 0.01 % uint16, pressure kPa-ish int16, concentrations are
`single` float with a `MeasurementUnit`) — the unit conversion table belongs to the
Matter layer, never to a sensor glue file.

Also worth wiring on endpoint 1: `Air Quality` enum from `aq_index`, plus the
Peak/Average measurement attributes only if you actually want to maintain the
windows they imply.

## 11. Power (R4)

Not optimized now, but nothing done now should have to be undone later:

- **Already free**: every thread blocks on a queue or timer, so the idle thread runs
  `WFI` and the SoC drops to System ON idle between samples. No `k_busy_wait`, no
  polling loops, no 1 Hz reporting by default.
- **Structural**: sensor power gating expressed in devicetree (`vin-supply` →
  `regulator-fixed`), and every glue module implements `stop_measurement()`. The
  `warmup_ms` field in the descriptor exists precisely so the duty-cycled path is the
  same code path as the always-on one. A SEN5x fan at ~80 mA is the whole battery
  story; getting it right is a config change, not a rewrite.
- **Config-only later**: `CONFIG_PM_DEVICE` + `PM_DEVICE_RUNTIME` so drivers suspend
  themselves between samples; `lowpower.conf` flips OpenThread from FTD to
  MTD/SED with a poll period; longer `X` and report-on-change.
- **Stub now, fill later**: battery voltage via ADC (`voltage-divider`) and the
  Power Source cluster on EP0. Leave the module and the endpoint slot, empty.
- **Anti-goals**: do not add a tickless/PM hack, per-sensor threads, or logging in the
  sample path — all three are hard to remove later.

## 12. Reliability

- **Watchdog**: `platform/watchdog` owns the WDT channel; each long-lived thread
  registers and checks in. A supervisor work item feeds the dog only if every
  registered participant has checked in within its window.
- **Sensor faults**: bounded retries with exponential backoff, I²C bus recovery, then
  power-cycle the rail if one exists; quantities degrade `VALID → STALE → ERROR` and
  the corresponding attributes go NULL. One dead sensor must never affect the others
  or the Thread connection.
- **Staleness is explicit**: `aq_state` expires values older than
  `k * sample_period`, so a silently wedged sensor cannot report a stale value forever.
- **Fatal errors**: `CONFIG_RESET_ON_FATAL_ERROR`, reboot reason and boot counter in
  retained RAM/settings, surfaced over shell and optionally Matter diagnostics.

## 13. Build system, variants, DFU

- Root `CMakeLists.txt` stays thin: `add_subdirectory` per module,
  `zephyr_iterable_section(NAME aqs_sensor ...)` for the registry, ZAP glue include.
- Per-module `CMakeLists.txt` using `zephyr_library_sources_ifdef(CONFIG_AQS_SENSOR_X ...)`
  so an unselected sensor contributes zero bytes.
- Variants by fragment, not by branch:
  `west build -b aqs_v1_nrf52840 -- -DEXTRA_CONF_FILE="configs/release.conf;configs/dfu-ota.conf"`
- **Flash budget is the real risk on nRF52840**: MCUboot + Matter + OpenThread + OTA
  secondary slot is tight. Measure early, with `release.conf`. If OTA does not fit,
  `dfu-smp.conf` (BLE SMP) is the fallback, and the decision stays a build variant
  rather than an architectural change.
- `VERSION` feeds both MCUboot image version and Matter software version — one source.

## 14. Testing

| Level | Where | How |
|---|---|---|
| Pure logic — `aq_index`, `aq_filter`, unit conversion, staleness | `tests/*` | ztest on `native_sim`, no hardware, runs in CI in seconds |
| Sensor scheduling | `tests/sensor_hub` | fake `sensor_driver_api` device that returns scripted values and injectable errors; asserts backoff, cadence, status transitions |
| Full pipeline without sensors | `glue/sim.c` | `CONFIG_AQS_SENSOR_SIM=y` synthesizes plausible drifting values, so the whole path incl. Matter can be exercised on a bare DK. Worth building first, before any real sensor. |
| Integration | on target | shell `aqs read` / `aqs sensors`, `chip-tool` reads and subscriptions |

The reason the logic layer is C and Matter-free is exactly this table — anything that
needs the CHIP stack to test is effectively untested.

## 15. Suggested migration path from the current tree

Written without having read `src/` yet, so treat as a proposal to reconcile:

1. Land `include/aqs/{quantity,value,state}.h` and `aq/aq_state.c`. Nothing else
   changes yet.
2. Introduce `sensor_hub` + the `AQS_SENSOR_DEFINE` registry with `sim.c` as the only
   sensor. Prove sample → state → Matter attribute end to end.
3. Move existing sensor handling from `components/sensors.c` into one glue file per
   part, one at a time, deleting from the old file as you go.
4. Reduce the existing Matter mapping (`air_quality_mapper`, `matter_handler`) to
   `matter_reporting` + `matter_endpoints`, with the unit conversion table in one place.
5. Add `settings_store` and move the report interval from Kconfig-only to
   Kconfig-default + persisted setting; add the shell command.
6. Split `prj.conf` into `prj.conf` + `configs/*.conf`; add `release.conf` and measure
   the flash budget.
7. Add `watchdog` and per-sensor backoff last, once the happy path is stable.

Each step is independently shippable and leaves the firmware working.

## 16. Open questions for you

1. Which sensors are actually in play (SCD4x? SEN5x? BME680/688 with BSEC? SGP4x?)? BSEC
   in particular is a licensed blob with its own state persistence needs and would get
   its own glue module and a settings key.
2. nRF52840 specifically, or could a 53/54 be on the table? It changes the flash budget
   conversation and whether Matter OTA is comfortable.
3. Is remote (Matter-side) configuration of `X` a requirement, or is
   commissioning-time + subscription control enough?
4. FTD or MTD for the Thread role on the USB-powered version? FTD is friendlier to the
   mesh; MTD is the battery path, and it is cheap to keep both as fragments.
5. Does one binary need to cover several hardware variants, or is a build per product?
   That decides §10's superset-ZAP question.

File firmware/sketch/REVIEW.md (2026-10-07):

# Current firmware vs. the proposed architecture

Review of the tree as of branch `feat-redesign` (commit `f01761f`), against
[`ARCHITECTURE.md`](ARCHITECTURE.md). ~1500 lines of application code.

## Verdict

The **shape** is closer to the plan than I expected: module boundaries are real, the
C/C++ wall is in the right place, the Matter endpoint split matches, and sensors are
already Zephyr `sensor` devices rather than hand-rolled I²C. What is missing is
everything that makes the structure *hold* as sensors are added: the sensor layer is a
hand-maintained `#ifdef` matrix with cross-sensor coupling through file-scope globals,
there is one global cadence for parts with very different physics, and error states are
encoded as in-band magic values that reach the Matter attributes as plausible readings.

Roughly: good decomposition, no isolation.

## Already aligned with the plan

| Plan item | Status |
|---|---|
| Sensors via Zephyr `sensor_driver_api`, no raw I²C in app | Done — all five parts go through `sensor_sample_fetch`/`channel_get`/`attr_set` |
| C++ quarantined to the Matter boundary | Done — only `matter_handler.cpp` + `air_quality_mapper.cpp`, C headers use `extern "C"` |
| Separate endpoints per sensor device type | Done — T=1, RH=2, P=3, AirQuality=4; matches the proposal exactly |
| Delegate `Instance` for AirQuality / concentration clusters | Done, and correctly — the comments show this was learned the hard way |
| Module layout (`components/`, `utils/`, `drivers/`) with headers under `include/` | Done, close enough to the proposed `platform/sensing/aq/matter` split |
| Timed work on a dedicated workqueue, not the system WQ | Done |
| Deadline-aware rescheduling | Partially — `calculate_task_delay()` compensates for work duration |
| PowerSource cluster on EP0, `vbatt` divider + ADC channel in DT | Present in the data model and devicetree already; no code behind either |
| `CONFIG_PM_DEVICE=y` | Set, but nothing calls `pm_device_action_run()` |

## Findings, worst first

### 1. Matter attributes are written without holding the CHIP stack lock

`update_cluster_states()` ([matter_handler.cpp:112](../src/components/matter_handler.cpp#L112))
calls `TemperatureMeasurement::Attributes::MeasuredValue::Set()`,
`sCarbonDioxideInstance.SetMeasuredValue()` and `sAirQualityInstance.UpdateAirQuality()`
directly from the `periodic_task_work_q` thread. Those touch the attribute store and
the reporting engine, which the CHIP thread is also using. No `LockChipStack()`, no
`ScheduleWork()`.

This is the failure mode that shows up as rare, unreproducible faults once
subscriptions are active — exactly when it is hardest to debug. Fix:

```cpp
chip::DeviceLayer::PlatformMgr().ScheduleWork(WriteAll, reinterpret_cast<intptr_t>(copy));
/* or, if you must stay synchronous: */
chip::DeviceLayer::PlatformMgr().LockChipStack(); /* ... */ UnlockChipStack();
```

`ScheduleWork` is preferable — it also removes any chance of the sensor path blocking
behind the radio stack.

### 2. One failed sensor at boot silently disables the device

`init_air_quality_monitor()` returns on the first sensor that is not ready, so
`main()` returns before `matter_dispatch_tasks()`
([air_quality_monitor.c:161](../src/air_quality_monitor.c#L161),
[main.c:22](../src/main.c#L22)). Matter and Thread were already started, so the node
still joins the network and answers — but nothing ever pumps `Nrf::DispatchNextTask()`
and no measurement is ever taken. A single loose I²C part produces a device that looks
healthy and reports nothing, forever.

Per the plan, sensor readiness should be per-sensor state, not a boot gate: log it,
mark that sensor's quantities unavailable, carry on.

### 3. Sensor combinations that do not compile

The `#ifdef` matrix has cross-dependencies that are not expressed:

- `read_sgp40_data()` uses `temperature` and `humidity` for compensation
  ([sensors.c:187](../src/components/sensors.c#L187)), but those are declared inside
  `#ifdef CONFIG_ENABLE_SHT4X` ([sensors.c:18](../src/components/sensors.c#L18)).
  **SGP40 without SHT4X does not build.**
- In `update_cluster_states()`, `status` is declared under
  `#if defined(SHT4X) || defined(SCD4X)` ([matter_handler.cpp:119](../src/components/matter_handler.cpp#L119))
  and used under `#if defined(BMP390) || defined(BME680)` ([matter_handler.cpp:139](../src/components/matter_handler.cpp#L139)).
  **A pressure-only or BME680-only build does not build.**
- `asc_initial_period` / `asc_standard_period`
  ([sensors.c:32](../src/components/sensors.c#L32)) divide by
  `CONFIG_ADVERTISEMENT_INTERVAL / CONFIG_MEASUREMENTS_PER_INTERVAL / 1000`. Any
  configuration where the per-sample interval is under 1000 ms is a **compile-time
  division by zero**.

Five independent sensor flags is a 32-way build matrix that nobody will test by hand.
This is the concrete argument for the registry approach: with self-registering
descriptors there is no combinatorial surface, and cross-sensor compensation becomes
explicit data (`AQS_Q_TEMPERATURE` from *whichever* sensor provides it) instead of a
file-scope variable that may or may not exist.

### 4. Error states are published as plausible measurements

`-1.0f` is the in-band error sentinel, and `get_mean()` returns `-1.0f` if *any*
sample in the window is negative ([variable_buffer.c:53](../src/utils/variable_buffer.c#L53)).
Consequences:

- **-1 °C is a real temperature.** One sub-zero reading poisons the whole window, and a
  genuine error is indistinguishable from a cold room.
- `-1.0f` flows straight through to Matter: temperature reports as `-100` (i.e. -1 °C),
  and CO₂ as `MakeNullable(-1.0f)` — nullable, but populated with -1 ppm rather than
  actually null.
- Every measured-value attribute in use here is nullable. Null is the correct signal.

### 5. Uninitialized heap can be published as a reading

`init_buffers()` mallocs but never zeroes, and `get_mean()` always averages the full
window regardless of how many samples were written
([variable_buffer.c:13](../src/utils/variable_buffer.c#L13)). Meanwhile
`update_cluster_states()` publishes temperature and humidity whenever
`CONFIG_ENABLE_SHT4X || CONFIG_ENABLE_SCD4X` — but `read_scd4x_data()` only *logs* its
temperature and humidity; it never calls `set_value()`. So in an **SCD4X-only build the
device publishes uninitialized heap as temperature and humidity**.

Secondary: the window size is a compile-time constant, so `malloc` buys nothing over a
static array — and no malloc arena is configured in `prj.conf`, so the allocation's
success depends on libc defaults.

### 6. Pressure scaling looks 10× off

Zephyr's `SENSOR_CHAN_PRESS` is kPa; Matter's `PressureMeasurement::MeasuredValue` is
kPa × 10 (0.1 kPa resolution). The code does `pressure * 100`
([matter_handler.cpp:140](../src/components/matter_handler.cpp#L140)), which reports
~10132 for standard atmosphere instead of ~1013. The log line in `sensors.c` formats
the same value as if it were Pa (`val1 / 100` → "1.x hPa"), which suggests the unit was
genuinely ambiguous at the time. Worth confirming against the BMP390 driver and the
spec, then putting the conversion in exactly one place.

Also minor: `RelativeHumidityMeasurement::MeasuredValue` is `uint16`, cast here to
`int16_t`.

### 7. The ICD configuration contradicts the use case and the data model

`prj.conf` selects `OPENTHREAD_MTD` + `CHIP_ENABLE_ICD_SUPPORT` + `CHIP_ICD_LIT_SUPPORT`
with a 300 s slow poll and a 900 s idle mode — a long-idle, battery-style sleepy device.
The application meanwhile refreshes attributes every 5 s
(`ADVERTISEMENT_INTERVAL=5000`). Two problems:

- A 5 s refresh behind a 5-minute poll interval means most updates never leave the
  device promptly. The cadence you configure and the cadence a controller observes are
  unrelated right now.
- **The ZAP has no `IcdManagement` cluster on endpoint 0**, which a LIT ICD is required
  to expose. Enabled in Kconfig, absent from the data model.

For a USB-powered device, FTD (or at minimum a non-LIT MED with a short poll) is the
straightforward choice, with the ICD/LIT setup moved to the future `lowpower.conf`
fragment. That is precisely the split the plan proposes; here both configurations are
half-applied at once.

### 8. One global cadence for parts with different physics

`ADVERTISEMENT_INTERVAL / MEASUREMENTS_PER_INTERVAL` is *the* sampling interval for
everything. But the SCD4x has a 5 s measurement period, and Sensirion's gas index
algorithm is specified around ~1 s sampling with only a narrow supported range —
`GasIndexAlgorithm_init_with_sampling_interval()` is handed
`ADVERTISEMENT_INTERVAL / MEASUREMENTS_PER_INTERVAL / 1000`
([sensors.c:69](../src/components/sensors.c#L69)), which at the Kconfig default of
300000/5 is **60 s**. At that interval the VOC index output is not meaningful. Worth
checking against the algorithm documentation, but the structural point stands: sampling
cadence belongs to the sensor, reporting cadence belongs to the application.

### 9. Cross-sensor coupling is implicit and order-dependent

SGP40 compensation needs SHT4X's values; SCD4x pressure compensation needs BMP390's.
Both work only because of the order of the `#ifdef` blocks in `read_sensors()` and
shared file-scope `sensor_value` variables. Nothing declares the dependency, and
reordering the blocks silently degrades accuracy rather than failing. A shared state
keyed by *quantity* rather than by *sensor* makes this explicit and order-independent.

### 10. "X seconds" is build-time only

`CONFIG_ADVERTISEMENT_INTERVAL` is a Kconfig integer baked into the image — and used at
compile time in static initializers, so it cannot easily become runtime-settable
without unpicking those. `CONFIG_SETTINGS`/`SETTINGS_RUNTIME` are already enabled in
`prj.conf` but unused by the application. The requirement "configurable reporting
interval" is not met yet in any operational sense.

### 11. Configuration source of truth is split three ways

Every sensor has an app flag (`CONFIG_ENABLE_SHT4X`), a driver flag (`CONFIG_SHT4X`),
and a devicetree `status`, all maintained by hand:

- Right now the overlay marks sht4x/sgp40/scd41/bme680 `okay` and the drivers are built,
  while **all five `CONFIG_ENABLE_*` are `n`** — so drivers initialize at boot, consume
  RAM and bus time, and are never read.
- `CONFIG_ENABLE_BMP390` gates a driver whose actual symbol is `CONFIG_BMP388`.
- Nothing prevents `CONFIG_ENABLE_SHT4X=y` with `CONFIG_SHT4X=n`.
- `CONFIG_BME680=n` appears twice, with different explanatory comments.

The plan's rule — devicetree decides existence, `depends on DT_HAS_<compat>_ENABLED`,
`select` the driver symbol — collapses this to one knob per sensor.

### 12. No `IcdManagement`, no `ThreadNetworkDiagnostics`

Worth adding the latter regardless; it is the cheapest field-debugging tool for a Thread
node, and the ZAP is where it has to happen.

### 13. Robustness gaps

- No watchdog (`CONFIG_WATCHDOG` absent), no `CONFIG_RESET_ON_FATAL_ERROR`.
- No retry, backoff, or bus recovery: a sensor that starts failing simply fails on every
  cycle, at full rate, forever.
- No timestamps or staleness anywhere, so a wedged sensor's last good value is
  republished indefinitely as current.
- `uart0` is `status = "disabled"` in the overlay while `CONFIG_UART_CONSOLE=y` and
  `CONFIG_LOG=y` — worth confirming the log output actually goes somewhere, because all
  the diagnostics above depend on it.

### 14. Build and hygiene

- `FILE(GLOB_RECURSE ...)` over `src/**` ([CMakeLists.txt:14](../CMakeLists.txt#L14))
  means anything dropped into the tree is compiled, and new files need a manual CMake
  re-run. It currently sweeps in both `air_quality_mapper.c` and
  `air_quality_mapper.cpp`, plus the `zap-generated/*.cpp` that
  `ncs_configure_data_model()` also adds. Explicit `zephyr_library_sources_ifdef()` per
  module is both safer and how per-sensor conditional compilation should be expressed.
- `include_directories()` is global; prefer `target_include_directories(app PRIVATE …)`.
- `include(zap_helpers.cmake)` appears twice (lines 30 and 32).
- Dead code: `warm_up_sgp40()` (static, never called — should be warning), all of
  `air_quality_mapper.c`, `get_latest()`, `free_buffers()`, `CONFIG_SENSOR_WARMUP_TIME_MS`.
  Note that the *warm-up* concept was clearly intended and then dropped; in the plan it
  is a first-class field on the sensor descriptor.
- `src/matter/default_zap/aqs.zap~` (editor backup) and `bin/*.uf2` are in the tree.
- `read_sensors()` is declared `int read_sensors();` — unprototyped in C.
- `int success = true;` in `read_sensors()`.
- README still describes BLE data transfer, NCS 2.9, and an `include/config.h` that does
  not exist.
- `NCS_SAMPLE_MATTER_LEDS=y` + `DK_LIBRARY=y` gives Nordic's board module ownership of
  the same LED GPIOs as `led_controller.c`. Dormant only because
  `CONFIG_ENABLE_EVENT_LED=n`.

## Structural differences worth deciding on

| Dimension | Now | Plan |
|---|---|---|
| Sensor addition cost | edit `sensors.c` (init + read + dispatch), `matter_handler.cpp`, `variable_buffer.h` enum, Kconfig, prj.conf, overlay | one glue file + DT node + one Kconfig symbol |
| Build matrix | 2⁵ hand-tested combinations, several known-broken | combinations are data, not preprocessor branches |
| Cadence | one interval for all sensors and for reporting | per-sensor sampling, independent reporting interval |
| Value representation | bare `float`, `-1.0f` = error | value + status + timestamp + provenance |
| Cross-sensor compensation | order-dependent file-scope globals | shared state keyed by quantity |
| Matter thread safety | unlocked writes from a workqueue | `ScheduleWork` only |
| Unit conversion | inline at each call site | one table at the Matter boundary |
| New consumers (the e-paper display already in DT!) | must edit the periodic task | add a zbus observer |
| Testability | none possible without the CHIP stack | logic layer runs on `native_sim` |

Note the `ssd1680` e-paper display and the `vbatt` divider are already in the
devicetree with no code behind them. Both are exactly the "second consumer" and "future
power concern" the decoupled state layer is meant to accommodate.

## Suggested order of work

Ordered by risk removed per unit of effort, not by architectural purity:

1. **`ScheduleWork` for all Matter writes** (§1). Small, self-contained, removes a
   real concurrency hazard.
2. **Don't abort boot on sensor init failure** (§2). A few lines.
3. **Fix the SCD4X-only uninitialized-heap publish and the `-1.0f` sentinel** (§4, §5) —
   introduce `struct aqs_value { float; status; timestamp; }` and write NULL for
   anything not valid. This is the first real step of the redesign and it pays for
   itself immediately.
4. **Decide FTD vs. ICD** (§7) and make `prj.conf` internally consistent; add
   `IcdManagement` to the ZAP if LIT stays.
5. **Verify the pressure scaling** (§6).
6. **Introduce the sensor registry** (§3, §8, §9) and migrate parts one at a time,
   starting with the simulated sensor so the pipeline is testable with no hardware.
7. **Move the reporting interval into settings** (§10), which requires removing
   `CONFIG_ADVERTISEMENT_INTERVAL` from static initializers first.
8. **Collapse the three-way sensor configuration** to devicetree-driven (§11).
9. Watchdog, backoff, staleness (§13); CMake and hygiene cleanup (§14).

Steps 1–5 are bug fixes worth doing whether or not the redesign happens.

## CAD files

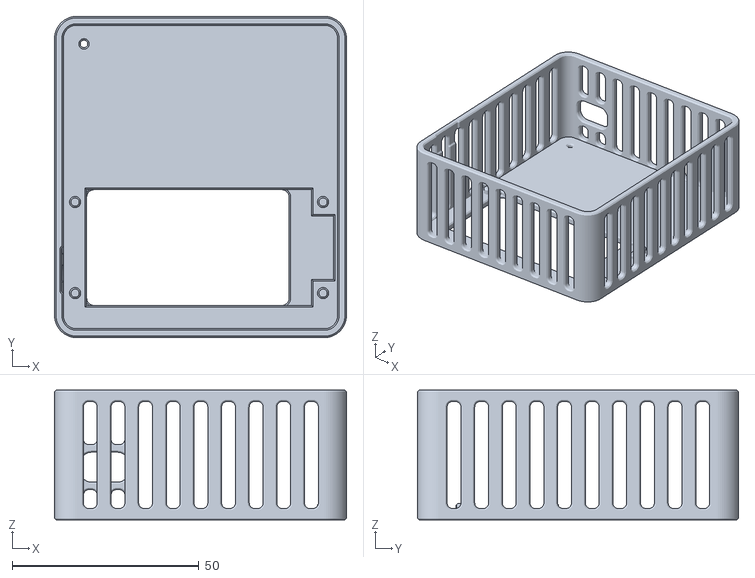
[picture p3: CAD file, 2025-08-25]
enclosure/enclosure_top.stl
78.2 x 86.1 x 34.7

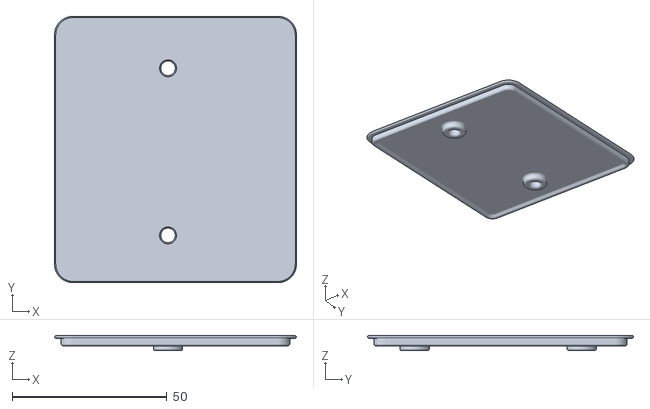
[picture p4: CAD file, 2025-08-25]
enclosure/enclosure_bottom.stl
78.2 x 86.1 x 5.00

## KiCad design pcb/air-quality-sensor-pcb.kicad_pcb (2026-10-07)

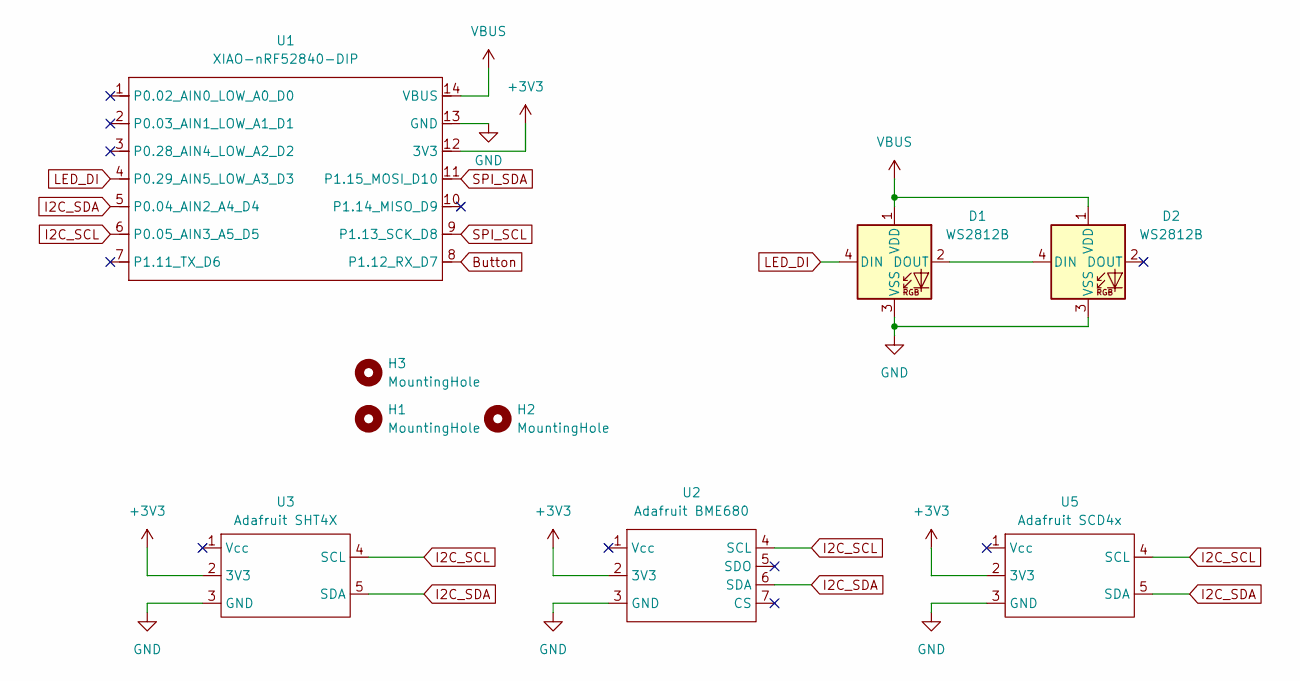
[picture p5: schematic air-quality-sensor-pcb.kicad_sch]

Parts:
D1, D2: WS2812B; LED_WS2812B_PLCC4_5.0x5.0mm_P3.2mm
H1, H2, H3: MountingHole; MountingHole_3.2mm_M3
U1: XIAO-nRF52840-DIP
U2: Adafruit BME680; adafruit_bme680
U3: Adafruit SHT4X; adafruit_sht4x
U5: Adafruit SCD4x; adafruit_scd4x

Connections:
+3V3: U1.12 (3V3), U2.2 (3V3), U3.2 (3V3), U5.2 (3V3)
Button: U1.8 (P1.12_RX_D7)
GND: D1.3 (VSS), D2.3 (VSS), U1.13 (GND), U2.3 (GND), U3.3 (GND), U5.3 (GND)
I2C_SCL: U1.6 (P0.05_AIN3_A5_D5), U2.4 (SCL), U3.4 (SCL), U5.4 (SCL)
I2C_SDA: U1.5 (P0.04_AIN2_A4_D4), U2.6 (SDA), U3.5 (SDA), U5.5 (SDA)
LED_DI: D1.4 (DIN), U1.4 (P0.29_AIN5_LOW_A3_D3)
unnamed: D1.2 (DOUT), D2.4 (DIN)
SPI_SCL: U1.9 (P1.13_SCK_D8)
SPI_SDA: U1.11 (P1.15_MOSI_D10)
VBUS: D1.1 (VDD), D2.1 (VDD), U1.14 (VBUS)

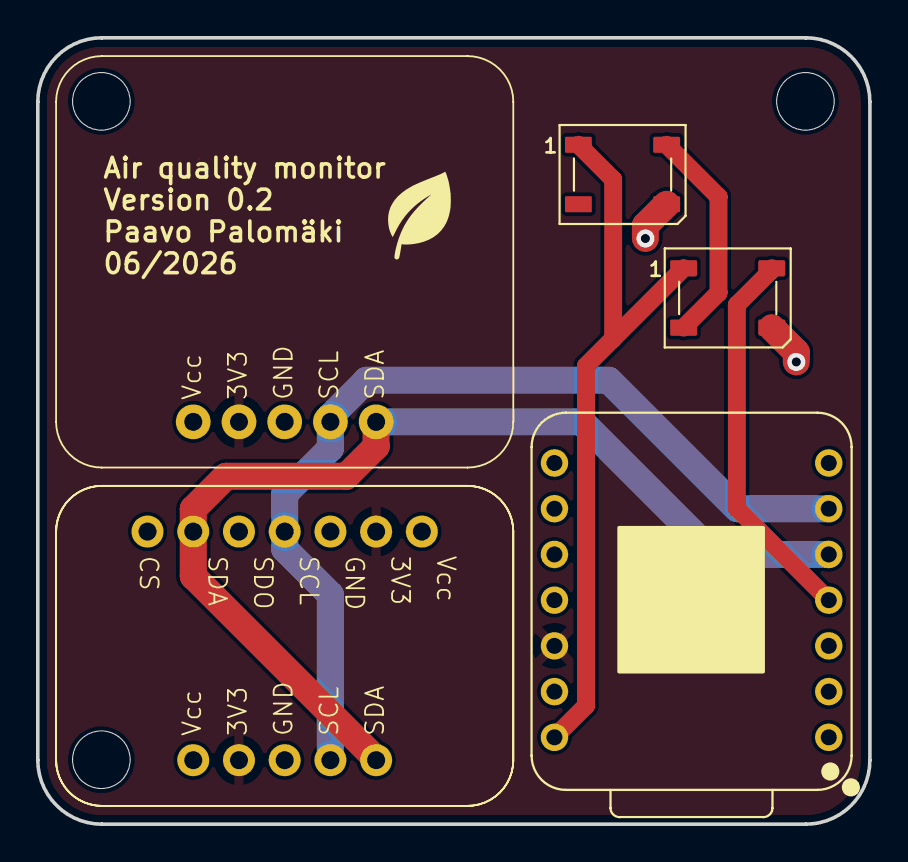
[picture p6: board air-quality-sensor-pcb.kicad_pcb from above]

Board: 2 copper layers, 46.2 x 43.7 mm, 9 parts (0 on the bottom side), 7 nets.

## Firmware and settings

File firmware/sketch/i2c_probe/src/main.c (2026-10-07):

#include <zephyr/kernel.h>
#include <zephyr/device.h>
#include <zephyr/drivers/i2c.h>
#include <zephyr/logging/log.h>

LOG_MODULE_REGISTER(i2c_probe);

#define I2C_NODE DT_NODELABEL(i2c1)

/** @brief Addresses this project expects to find, probed individually */
static const struct {
	uint16_t addr;
	const char *name;
} expected[] = {
	{0x44, "sht4x"},
	{0x59, "sgp40"},
	{0x62, "scd41"},
	{0x77, "bmp390/bme680"},
};

/**
 * @brief Address one device and report whether it acknowledges
 *
 * Uses the zero length write that i2c scan uses, which the nRF TWI/TWIM
 * peripherals support.
 *
 * @param bus I2C controller
 * @param addr 7 bit address to probe
 * @return 0 if the device acknowledged, negative errno otherwise
 */
static int probe(const struct device *bus, uint16_t addr)
{
	uint8_t dummy;
	struct i2c_msg msg = {.buf = &dummy, .len = 0U, .flags = I2C_MSG_WRITE | I2C_MSG_STOP};

	return i2c_transfer(bus, &msg, 1, addr);
}

int main(void)
{
	const struct device *bus = DEVICE_DT_GET(I2C_NODE);

	if (!device_is_ready(bus)) {
		LOG_ERR("%s is not ready, the controller itself failed to initialize.", bus->name);
		return 0;
	}

	LOG_INF("Probing %s at %u Hz on SDA P0.04 / SCL P0.05.", bus->name,
		DT_PROP(I2C_NODE, clock_frequency));

	while (1) {
		int found = 0;

		for (uint16_t addr = 0x08; addr <= 0x77; addr++) {
			if (probe(bus, addr) == 0) {
				LOG_INF("  0x%02x acknowledged", addr);
				found++;
			}
		}

		LOG_INF("%d device(s) responded on the full scan.", found);

		ARRAY_FOR_EACH(expected, i) {
			int rc = probe(bus, expected[i].addr);

			LOG_INF("  %-14s 0x%02x -> %s (err %d)", expected[i].name, expected[i].addr,
				rc == 0 ? "ACK" : "no ACK", rc);
		}

		k_sleep(K_SECONDS(5));
	}

	return 0;
}

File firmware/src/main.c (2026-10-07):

#include <air_quality_monitor.h>

#include <zephyr/logging/log.h>

LOG_MODULE_REGISTER(app);

int main(void)
{
	LOG_INF("Initializing and starting the air quality monitor.");
	int rc = 0;

	// Initialize the air quality monitor
	rc = init_air_quality_monitor();
	if (rc != 0)
	{
		LOG_ERR("Air quality monitor initialized with errors (err %d), continuing.", rc);
	}

	// Start the air quality monitor
	LOG_INF("Initialization complete, starting the monitoring.");
	rc = start_air_quality_monitor();
	if (rc != 0)
	{
		LOG_ERR("Error while starting the air quality monitor (err %d).", rc);
	}

	return rc;
}

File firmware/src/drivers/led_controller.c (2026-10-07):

#include <drivers/led_controller.h>

#include <zephyr/logging/log.h>
#include <zephyr/drivers/gpio.h>

#define LED_RED_NODE DT_ALIAS(led2)
#define LED_GREEN_NODE DT_ALIAS(led1)
#define LED_BLINK_INTERVAL 50 // Milliseconds

LOG_MODULE_REGISTER(led_controller);

/**
 * @brief Struct for containing led related information
 *
 */
typedef struct
{
    led_color_t color;
    int remaining_toggles;
    bool is_on;
    struct k_timer timer;
} led_blink_ctx_t;

static led_blink_ctx_t blink_ctx;

// GPIO specs from devicetree
static const struct gpio_dt_spec led_red_spec = GPIO_DT_SPEC_GET(LED_RED_NODE, gpios);
static const struct gpio_dt_spec led_green_spec = GPIO_DT_SPEC_GET(LED_GREEN_NODE, gpios);

/**
 * @brief Handles LED blinking
 *
 * @param timer
 */
static void blink_handler(struct k_timer *timer)
{
    if (blink_ctx.remaining_toggles <= 0)
    {
        set_led(LED_OFF_COLOR);
        k_timer_stop(&blink_ctx.timer);
        return;
    }

    set_led((blink_ctx.is_on) ? LED_OFF_COLOR : blink_ctx.color);
    blink_ctx.remaining_toggles--;

    blink_ctx.is_on = !blink_ctx.is_on;
}

int init_led_controller(void)
{
    if (!gpio_is_ready_dt(&led_red_spec) || !gpio_is_ready_dt(&led_green_spec))
    {
        LOG_ERR("LED devices not ready.");
        return -ENXIO;
    }

    int rc = 0;
    rc = gpio_pin_configure_dt(&led_red_spec, GPIO_OUTPUT_INACTIVE);
    if (rc != 0)
    {
        LOG_ERR("GPIO configuration for red led failed (err %d).", rc);
        return rc;
    }
    rc = gpio_pin_configure_dt(&led_green_spec, GPIO_OUTPUT_INACTIVE);
    if (rc != 0)
    {
        LOG_ERR("GPIO configuration for green led failed (err %d).", rc);
        return rc;
    }
    k_timer_init(&blink_ctx.timer, blink_handler, NULL);
    return 0;
}

void blink_led(led_color_t color, int count)
{
    // Stop current blinking before starting new one
    k_timer_stop(&blink_ctx.timer);

    blink_ctx.color = color;
    blink_ctx.remaining_toggles = count * 2; // on + off
    blink_ctx.is_on = false;

    k_timer_start(&blink_ctx.timer, K_NO_WAIT, K_MSEC(LED_BLINK_INTERVAL));
}

void set_led(led_color_t color)
{
    gpio_pin_set_dt(&led_red_spec, (color & LED_RED) ? LED_ON : LED_OFF);
    gpio_pin_set_dt(&led_green_spec, (color & LED_GREEN) ? LED_ON : LED_OFF);
}

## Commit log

2025-02-12 Initial commit with arduino sketch and pcb sketch
    [air-quality-sensor-pcb.kicad_pcb, air-quality-sensor-pcb.kicad_sch]
2025-03-30 Current working version, BAS & ESS service with notifications
2025-03-31 Battery simulation
2025-04-03 Enable low power mode by disabling external flash manually
2025-04-05 Implement filter list, WIP does not work with phones
2025-04-13 Pick components for PCB
    [air-quality-sensor-pcb.kicad_pcb, air-quality-sensor-pcb.kicad_sch]
2025-04-17 Redo debug led, implement state and event handlers, BT state
2025-04-30 Reduce duplication in sensor reading
2025-05-02 Use Pa for pressure in code, output hPa to bluetooth
2025-05-02 Add units to sensor reading prints
2025-05-04 Implement battery monitor fort reading the battery voltage and calculating the percentage
2025-05-06 Fix print for % sign
2025-05-06 Add possibility to disable the battery monitor
2025-05-06 Convert pressure correctly
2025-05-10 Setup EPD driver (driver setup, implementation WIP)
2025-05-10 Simplify sensors define usage
2025-05-17 PCB decign v0.1
    [air-quality-sensor-pcb.kicad_pcb, air-quality-sensor-pcb.kicad_sch]
2025-05-18 Idle mode power saving improvements
2025-05-25 Cleanup unused variables from commands, cleanup the content of air_quality_monitor and repurpose state_handler to actually handle state related stuff like activating/suspending devices
2025-06-07 Fix SGP40 not giving values after idle mode by mock measurements and letting the sensor warm up and measuring it last
2025-06-07 Add raspberry pi address to the whitelisted addresses if whitelisting is used
2025-06-24 Reorganize folder structure, add script for reading sensor output data on a RPI with Dockerfile and compose file, improve READMEs
    [air-quality-sensor-pcb.kicad_pcb, air-quality-sensor-pcb.kicad_sch]
2025-06-25 Fix printing string for log
2025-06-28 Add warm up time configuration for sensors
2025-06-29 Handle problematic readings by not printing them on EPD or sending them to MQTT server
2025-06-30 Use more fitting already existing device for battery voltage reading, add driver for bq25100 for gpios
2025-06-30 Clean up error handling and logging to be more concise accross the board
    [led_controller.c, main.c]
2025-07-08 Print raw value in logs in case of processed value published forward
2025-07-08 Add pcb step file
    [air-quality-sensor-pcb.step]
2025-07-20 Implement pairing with device with automatic bond replacement
2025-07-20 Use whitelist for paired devices, encrypt data
2025-08-25 Add step and stl files for the enclosure design
    [air-quality-sensor-pcb.step, enclosure_bottom.stl, enclosure_top.stl]
2025-08-25 Increase warmup time for better performance of SGP40 sensor, to keep consumption low, lower the measurements per interval
2026-01-13 Support pressure data also with BME680
2026-01-13 Enable warmup only when using SGP40 sensor
2026-01-13 Add selected binaries to repository, add device specific prj.conf files
2026-01-13 Add prometheus port variable for supporting multiple devices, add another device to docker compose file
2026-01-14 Fix pressure not being sent when using BME680
2026-01-15 Print timestamps
2026-06-06 New PCB design
    [air-quality-sensor-pcb.kicad_pcb, air-quality-sensor-pcb.kicad_sch]
2026-07-14 Add support for esp32c6
2026-07-14 Revert "Add support for esp32c6"
    This reverts commit cb8e617e5a186d5fc1b2b5de02b1c8738d7fb1ee.
    [led_controller.c]
2026-07-19 Remove display and battery monitor
2026-09-05 All sensors build
2026-09-10 Keep the device alive when a sensor fails to initialize
    [main.c]
2026-09-10 Guard cross-sensor values so any sensor combination builds and runs
2026-09-10 Record SCD4x temperature and humidity, and zero the value buffers
2026-09-10 Track measurement validity instead of using -1.0f as an error marker
2026-09-10 Normalize pressure to hPa and fix the reported and compensated values
2026-09-10 Silence unused-variable warnings when no sensor is enabled
2026-09-10 Select fallback sensor sources at compile time
2026-09-11 Remove the e-paper display and battery divider from the overlays
2026-09-11 Disable the UART console, uart0 is disabled in the overlays
2026-09-11 Disable the ICD tuning on the USB powered build
2026-09-11 Gate sensor configuration on devicetree
2026-09-11 Let the board configure the CDC ACM console
2026-09-11 Fix the SCD4x self calibration periods
2026-09-12 Use LED controller only for green and red LEDs
2026-09-12 Invert blue led functionality for matter to ahve it off most of the time
2026-09-12 Update the README to match the current firmware
2026-09-12 Use automatic sampling mode for SCD41 since driver does not support offset on single shot mode
2026-09-12 Use milli degrees to set temperature offset for SCD4X
2026-09-12 Mount D-Bus into the Matter server for mDNS discovery
2026-09-12 Document the BME680 as a temperature and humidity source
2026-09-12 Use the BME680 as a temperature and humidity source
2026-09-15 Derive a per-board Matter identity from the SoC device ID
2026-09-15 Add a power cycle factory reset for boards without a button
2026-10-07 Add the ESP32-C6 port plan
2026-10-07 Port the firmware to the XIAO ESP32-C6 on esp-matter
2026-10-13 Log Thread link diagnostics and reboot when stuck detached
